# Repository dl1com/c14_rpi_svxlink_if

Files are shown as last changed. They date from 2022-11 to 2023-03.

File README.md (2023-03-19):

# c14_rpi_svxlink_if
Raspberry Pi Hat for SVXLink

This repository contains the code and instructions for a custom interface between radio transceivers and a Raspberry Pi running SVXLink.

## Repository contents
The repository contains the following files and directories:

* [c14_rpi_svxlink_if.kicad_pcb](./c14_rpi_svxlink_if.kicad_pcb): the KiCAD project for the custom PCB design.
* [LICENSE.md](./LICENSE.md): the license file for the repository (CC-BY-SA).
* README.md: this file.



## Features

The interface offers the following features:

* Generic DB9 connector for interfacing to transceiver(s)
* Isolated audio rx/tx and signal paths (PTT, Squelch)
* Audio levels can be set with potis
* Fan control output and tacho input
* Telemetry inputs:
  * ADS1115 ADC (i.e. for voltage or RSSI measurement)
  * I2C connectors (i.e. for temperature sensors)

We deliberately decided against placing a soundcard IC on the interface. We use an external, generic USB soundcard instead, as these type of soundcards are very easy and cheap to get on various market places.

## Signal mapping

### DB9 Connector

| Number | Name |
| --- | --- |
| 1 | SQL_DET- |
| 2 | SQL_DET+ |
| 3 | RSSI |
| 4 | RX_AUDIO- |
| 5 | RX_AUDIO+ |
| 6 | PTT_GND |
| 7 | PTT+ |
| 8 | TX_AUDIO- |
| 9 | TX_AUDIO+ |

### RPi

| GPIO | Pin | Function |
| --- | --- | --- |
| GPIO17  | 11  | PTT |
| GPIO22  | 15  | SQL Det. |
| GPIO18  | 12  | Fan Ctrl |
| GPIO24  | 18  | Fan Tacho  |

### Jumper

| JP  | Function |
| --- | --- |
| JP1 | Bypass PWM (always on)  |
| JP2 | Enable clipping diodes  |

## Usage

An example project which uses this board can be found at https://charly14.de/svxlink-installation-und-konfiguration/

## License
This repository is licensed under the CC-BY-SA. See the LICENSE file for details.

Concept ist based on the [SVXLink Interface by Aleksander, S65AL](http://lea.hamradio.si/~s57nan/ham_radio/svx_intf_rpi/svx_intf_rpi.html)

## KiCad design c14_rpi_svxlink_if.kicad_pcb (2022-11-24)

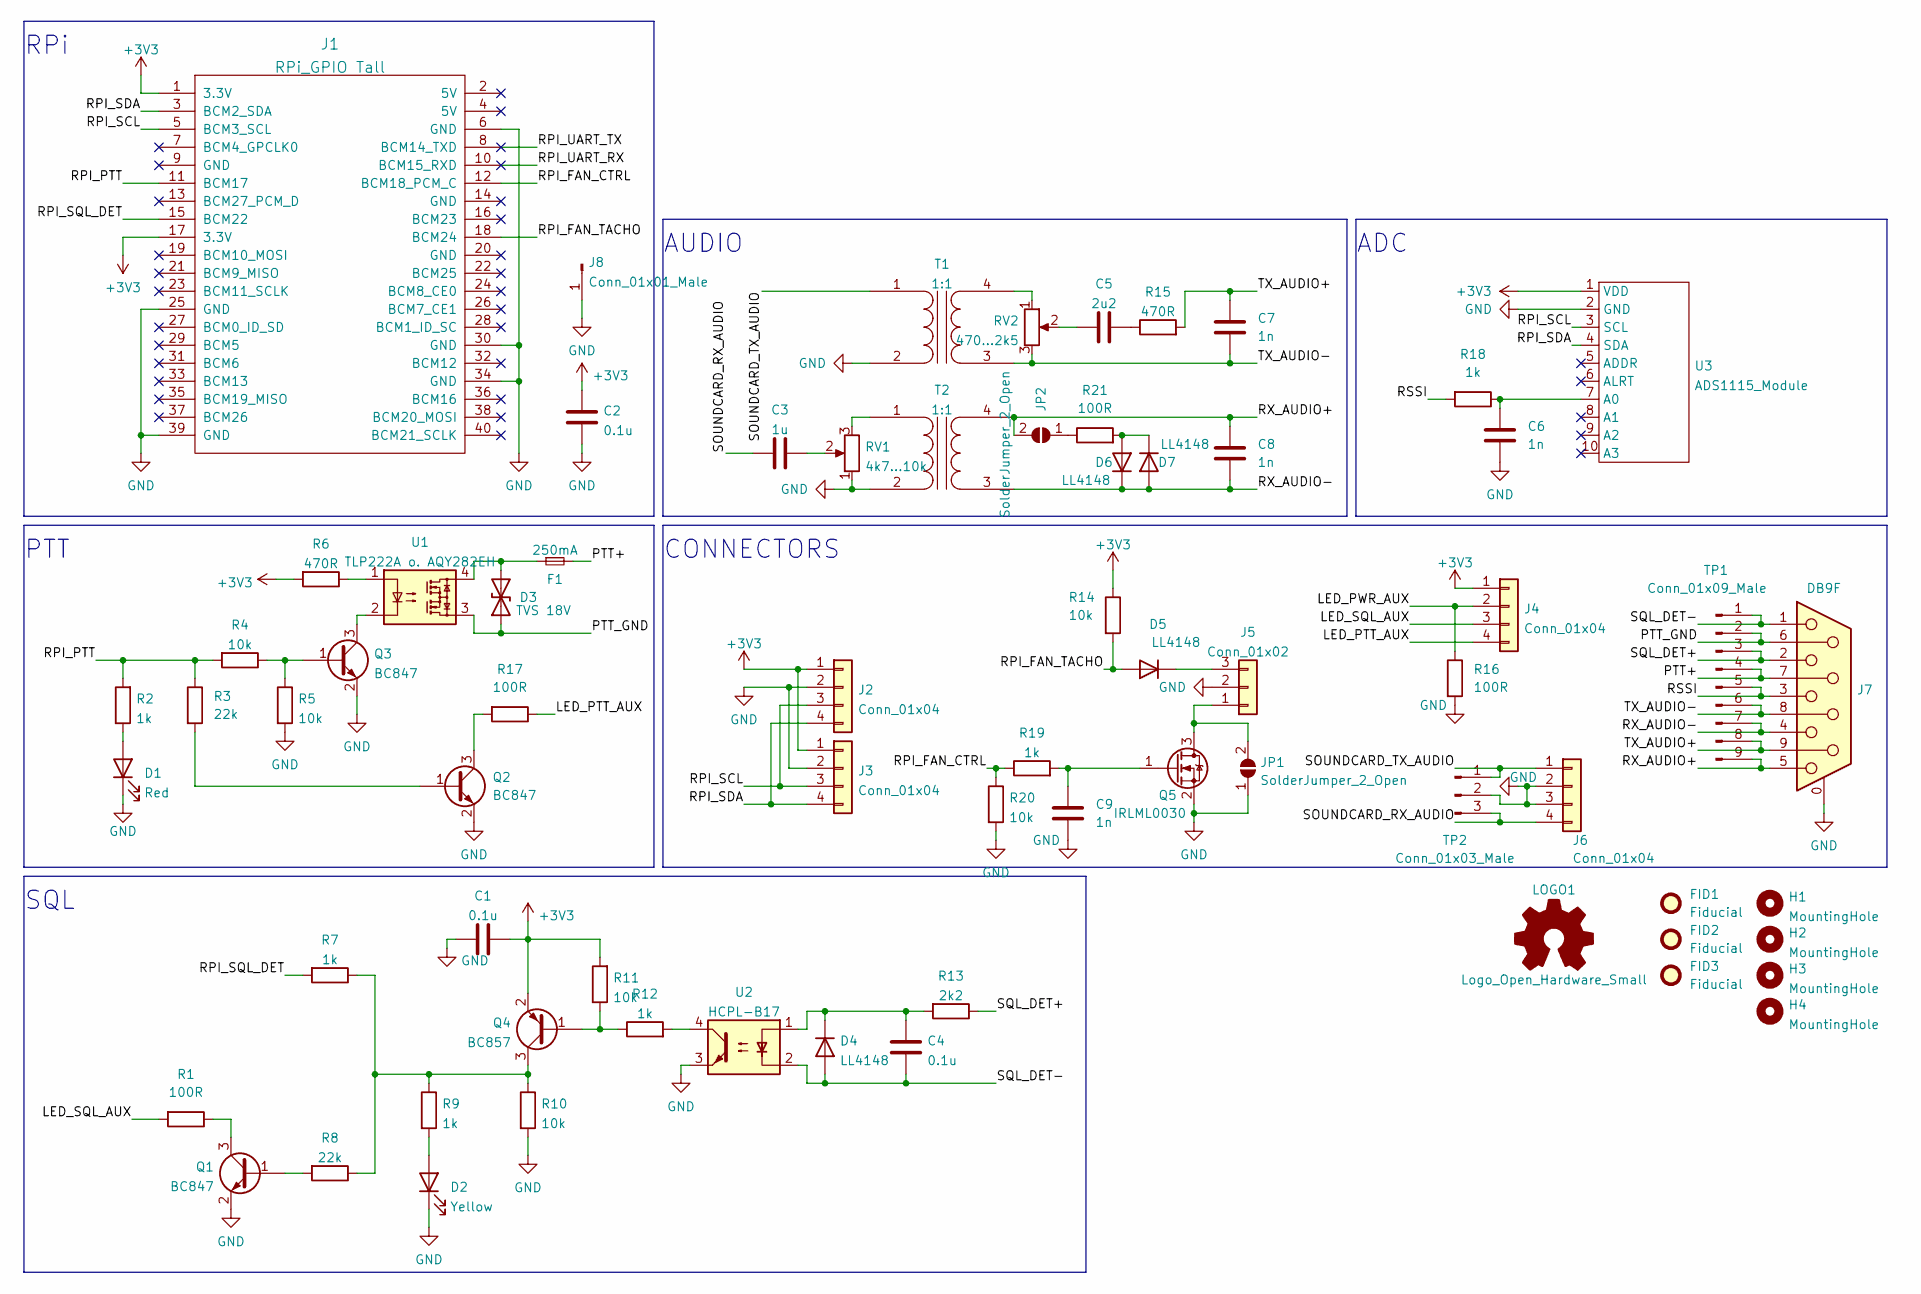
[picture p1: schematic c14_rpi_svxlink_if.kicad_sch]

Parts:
C1, C2, C4: 0.1u; C_0805_2012Metric_Pad1.18x1.45mm_HandSolder; PartNr_Mouser 603-CC805KRX7R9BB104
C3: 1u; C_Rect_L7.2mm_W4.5mm_P5.00mm_FKS2_FKP2_MKS2_MKP2; PartNr_Mouser 871-B32529C105J189
C5: 2u2; C_Rect_L7.2mm_W8.5mm_P5.00mm_FKP2_FKP2_MKS2_MKP2; PartNr_Mouser 80-R82CC4220Z370J
C6, C7, C8, C9: 1n; C_0805_2012Metric_Pad1.18x1.45mm_HandSolder; PartNr_Mouser 187-CL21B102KBANNNL
D1: Red; LED_0805_2012Metric_Pad1.15x1.40mm_HandSolder; PartNr_Mouser 755-SML-H12V8TT86C
D2: Yellow; LED_0805_2012Metric_Pad1.15x1.40mm_HandSolder; PartNr_Mouser 755-SML-H12Y8TT86C
D3: TVS 18V; D_SMA-SMB_Universal_Handsoldering; PartNr_Mouser 494-SMBJ18CAE3/TR13
D4, D5, D6, D7: LL4148; D_MiniMELF; PartNr_Mouser 512-LL4148
F1: 250mA; Fuse_1206_3216Metric_Pad1.42x1.75mm_HandSolder; PartNr_Mouser 576-1206L025YR
FID1, FID2, FID3: Fiducial; Fiducial_1mm_Mask3mm
H1, H2, H3, H4: MountingHole; RPi_Hat_Mounting_Hole; PartNr_Mouser --
J1: RPi_GPIO Tall; Pin_Header_Straight_2x20; PartNr_Mouser 485-1992
J2, J3, J4, J6: Conn_01x04; JST_XH_B4B-XH-A_1x04_P2.50mm_Vertical; PartNr_Mouser --
J5: Conn_01x02; JST_XH_B3B-XH-A_1x03_P2.50mm_Vertical
J7: DB9F; DSUB-9_Female_Horizontal_P2.77x2.84mm_EdgePinOffset7.70mm_H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; PartNr_Mouser 523-L77SDE09SA4CH3F
J8: Conn_01x01_Male; PinHeader_1x01_P2.54mm_Vertical
JP1, JP2: SolderJumper_2_Open; SolderJumper-2_P1.3mm_Open_TrianglePad1.0x1.5mm
LOGO1: Logo_Open_Hardware_Small; OSHW-Logo2_9.8x8mm_SilkScreen
Q1, Q2, Q3: BC847; SOT-23; PartNr_Mouser 771-BC847235
Q4: BC857; SOT-23; PartNr_Mouser 771-BC857/T3
Q5: IRLML0030; SOT-23; PartNr_Mouser 942-IRLML0030TRPBF
R1, R16, R17, R21: 100R; R_0805_2012Metric_Pad1.20x1.40mm_HandSolder; PartNr_Mouser 603-RC0805JR-07100RL
R2, R7, R9, R12, R18, R19: 1k; R_0805_2012Metric_Pad1.20x1.40mm_HandSolder; PartNr_Mouser 652-CR0805FX-1001ELF
R3, R8: 22k; R_0805_2012Metric_Pad1.20x1.40mm_HandSolder; PartNr_Mouser 603-RC0805FR-0722KL
R4, R5, R10, R11, R14, R20: 10k; R_0805_2012Metric_Pad1.20x1.40mm_HandSolder; PartNr_Mouser 603-RC0805JR-0710KL
R6, R15: 470R; R_0805_2012Metric_Pad1.20x1.40mm_HandSolder; PartNr_Mouser 652-CR0805FX-4700ELF
R13: 2k2; R_0805_2012Metric_Pad1.20x1.40mm_HandSolder; PartNr_Mouser 652-CR0805FX-2201ELF
RV1: 4k7...10k; Potentiometer_Vishay_TS53YL_Vertical; PartNr_Mouser 72-TS53YL-5K
RV2: 470...2k5; Potentiometer_Vishay_TS53YL_Vertical; PartNr_Mouser 72-TS53YL-500
T1, T2: 1:1; Transformer_NF_ETAL_P3324; PartNr_Mouser 652-LM-NP-1001-B1L
TP1: Conn_01x09_Male; PinHeader_1x09_P1.27mm_Vertical
TP2: Conn_01x03_Male; PinHeader_1x03_P1.27mm_Vertical
U1: TLP222A o. AQY282EH; DIP-4_W7.62mm; PartNr_Mouser AQY282EH
U2: HCPL-B17; DIP-4_W7.62mm; PartNr_Mouser 630-HCPL-817-06DE
U3: ADS1115_Module; ADS1115 Module; PartNr_Mouser --

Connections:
+3V3: C1.2, C2.1, J1.1 (3.3V), J1.17 (3.3V), J2.1, J3.1, J4.1, Q4.2 (E), R6.2, R11.2, R14.1, U3.1 (VDD)
/LED_PTT_AUX: J4.4, R17.1
/LED_PWR_AUX: J4.2, R16.1
/LED_SQL_AUX: J4.3, R1.2
/PTT+: F1.2, J7.7, TP1.4
/PTT_GND: D3.1 (A1), J7.6, TP1.2, U1.3
/RPI_FAN_CTRL: J1.12 (BCM18_PCM_C), R19.1, R20.1
/RPI_FAN_TACHO: D5.2 (A), J1.18 (BCM24), R14.2
/RPI_PTT: J1.11 (BCM17), R2.2, R3.1, R4.2
/RPI_SCL: J1.5 (BCM3_SCL), J2.3, J3.3, U3.3 (SCL)
/RPI_SDA: J1.3 (BCM2_SDA), J2.4, J3.4, U3.4 (SDA)
/RPI_SQL_DET: J1.15 (BCM22), R7.2
/RPI_UART_RX: J1.10 (BCM15_RXD)
/RPI_UART_TX: J1.8 (BCM14_TXD)
/RSSI: J7.3, R18.2, TP1.5
/RX_AUDIO+: C8.2, J7.5, JP2.2 (B), T2.4 (SB), TP1.9
/RX_AUDIO-: C8.1, D6.1 (K), D7.2 (A), J7.4, T2.3 (SA), TP1.7
/SOUNDCARD_RX_AUDIO: C3.2, J6.4, TP2.3
/SOUNDCARD_TX_AUDIO: J6.1, T1.1 (AA), TP2.1
/SQL_DET+: J7.2, R13.1, TP1.3
/SQL_DET-: C4.1, D4.2 (A), J7.1, TP1.1, U2.2
/TX_AUDIO+: C7.2, J7.9, R15.2, TP1.8
/TX_AUDIO-: C7.1, J7.8, RV2.3, T1.3 (SA), TP1.6
GND: C1.1, C2.2, C6.1, C9.1, D1.1 (K), D2.1 (K), J1.6 (GND), J1.25 (GND), J1.30 (GND), J1.34 (GND), J1.39 (GND), J2.2, J3.2, J5.2, J6.2, J6.3, J7.0 (PAD), J8.1, JP1.1 (A), Q1.2 (E), Q2.2 (E), Q3.2 (E), Q5.2 (S), R5.2, R10.2, R16.2, R20.2, RV1.1, T1.2 (AB), T2.2 (AB), TP2.2, U2.3, U3.2 (GND)
unnamed: C3.1, RV1.2
unnamed: C4.2, D4.1 (K), R13.2, U2.1
unnamed: C5.1, R15.1
unnamed: C5.2, RV2.2
unnamed: C6.2, R18.1, U3.7 (A0)
unnamed: D1.2 (A), R2.1
unnamed: D2.2 (A), R9.2
unnamed: D3.2 (A2), F1.1, U1.4
unnamed: D5.1 (K), J5.3
unnamed: D6.2 (A), D7.1 (K), R21.2
unnamed: J5.1, JP1.2 (B), Q5.3 (D)
unnamed: JP2.1 (A), R21.1
unnamed: Q1.1 (B), R8.2
unnamed: Q1.3 (C), R1.1
unnamed: Q2.1 (B), R3.2
unnamed: Q2.3 (C), R17.2
unnamed: Q3.1 (B), R4.1, R5.1
unnamed: Q3.3 (C), U1.2
unnamed: Q4.1 (B), R11.1, R12.1
unnamed: Q4.3 (C), R7.1, R8.1, R9.1, R10.1
unnamed: C9.2, Q5.1 (G), R19.2
unnamed: R6.1, U1.1
unnamed: R12.2, U2.4
unnamed: RV1.3, T2.1 (AA)
unnamed: RV2.1, T1.4 (SB)

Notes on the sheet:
ADC
CONNECTORS
SQL
RPi
PTT
AUDIO

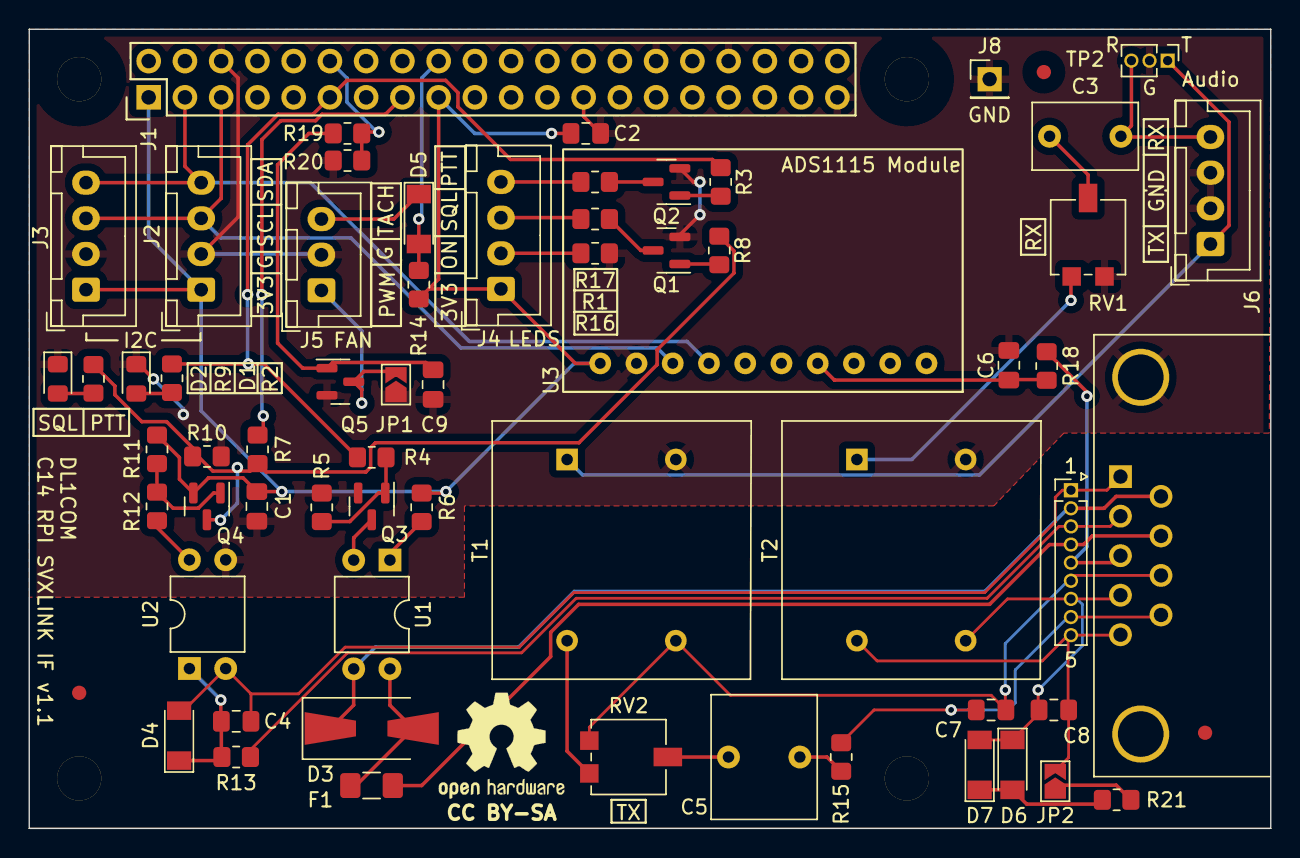
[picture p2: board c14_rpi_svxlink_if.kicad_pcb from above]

Board: 2 copper layers, 87.0 x 56.0 mm, 70 parts (0 on the bottom side), 47 nets.

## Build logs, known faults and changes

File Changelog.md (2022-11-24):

# Changelog
All notable changes to this project will be documented in this file.

The format is based on [Keep a Changelog](https://keepachangelog.com/en/1.0.0/),
and this project adheres to [Semantic Versioning](https://semver.org/spec/v2.0.0.html).

## [1.1] - 2022-11-23

### Added

* Fan PWM output
* Clipping diodes for Rx audio
* Fiducials for Pick n Place
* OSHW Logo and CC-BY-SA license

### Changed

* Fixed footprint for J7
* added some Cs in audio path

## [1.0] - 2022-04-09

Initial Version

### Known issues

* Wrong footprint for J7 (footprint is for male connector, BOM lists female)

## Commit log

2022-02-28 Layout fertig, DRC und Review fehlen
    [c14_rpi_svxlink_if.kicad_pcb, c14_rpi_svxlink_if.kicad_sch]
2022-04-09 Small preproduction changes
    [c14_rpi_svxlink_if.kicad_pcb, c14_rpi_svxlink_if.kicad_sch]
2022-04-09 Fix: Correct Footprint for J7 (M->F)
    [c14_rpi_svxlink_if.kicad_pcb, c14_rpi_svxlink_if.kicad_sch]
2022-04-09 Added Fiducials
    [c14_rpi_svxlink_if.kicad_pcb]
2022-04-09 Add License and OSHW logo
    [c14_rpi_svxlink_if.kicad_pcb]
2022-04-09 Add Open Collector for Fan Ctrl
    [c14_rpi_svxlink_if.kicad_pcb, c14_rpi_svxlink_if.kicad_sch]
2022-09-15 Neue Teile platziert, pre-1.1 bereit fuer Review
    [c14_rpi_svxlink_if.kicad_pcb, c14_rpi_svxlink_if.kicad_sch]
2022-09-18 ready for production
    [c14_rpi_svxlink_if.kicad_pcb, c14_rpi_svxlink_if.kicad_sch]
2022-11-24 last changes for 1.1
    [c14_rpi_svxlink_if.kicad_pcb, c14_rpi_svxlink_if.kicad_sch]
